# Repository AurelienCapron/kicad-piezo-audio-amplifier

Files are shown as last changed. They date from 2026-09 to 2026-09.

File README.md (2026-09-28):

# Chaîne d'Amplification Audio Piézoélectrique & PCB CMS (KiCad 9)





Conception, simulation SPICE, routage PCB en composants montés en surface (CMS) et caractérisation expérimentale d'une chaîne complète de conditionnement et d'amplification audio pour capteur piézoélectrique (guitare acoustique, contrebasse). Le système est alimenté en asymétrique (0V/5V) et réparti sur deux cartes électroniques : une première dédiée à la préamplification et à l'égalisation active (filtre de Baxandall), et une seconde intégrant une correction physiologique (*Loudness*) ainsi que deux étages de puissance sélectionnables (Classe AB et Classe D) pour piloter un haut-parleur de 8 Ω (2 W).

* **[Consulter le rapport complet de caractérisation et fiches de mesures (PDF)](docs/characterization_report.pdf)**

---

## Sommaire
1. [Architecture globale et cartes PCB réalisées](#architecture-globale-et-cartes-pcb-réalisées)
2. [Structure du dépôt](#structure-du-dépôt)
3. [Conception électronique détaillée (Cartes 1 et 2)](#conception-électronique-détaillée-cartes-1-et-2)
4. [Caractérisation expérimentale et résultats](#caractérisation-expérimentale-et-résultats)
5. [Nomenclature des composants principaux (BOM)](#nomenclature-des-composants-principaux-bom)
6. [Ouverture des fichiers de conception (KiCad 9)](#ouverture-des-fichiers-de-conception-kicad-9)

---

## Architecture globale et cartes PCB réalisées

Architecture de la chaîne audio

| Carte PCB 1 soudée (Préampli, Baxandall & Alim 5V) | Carte PCB 2 soudée (Loudness, Classe AB & Classe D) |
| :---: | :---: |
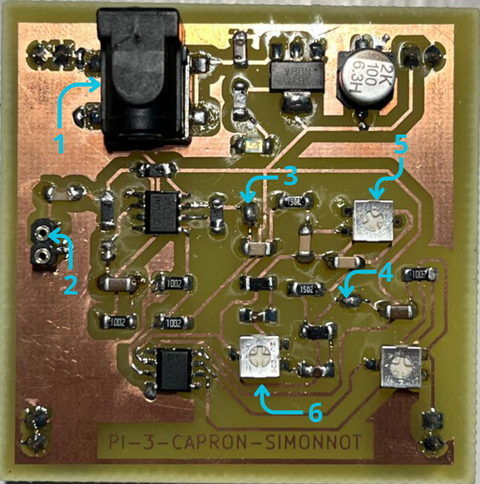
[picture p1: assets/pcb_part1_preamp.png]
PCB 1
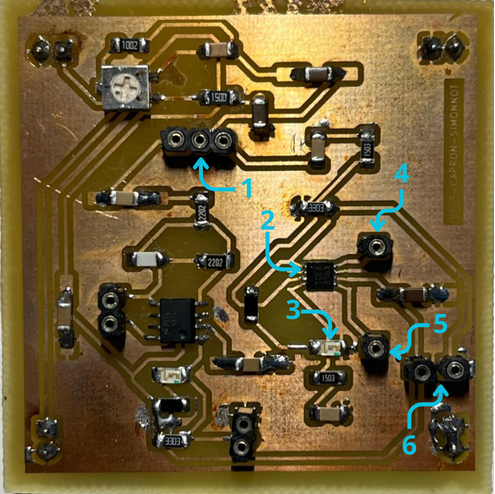
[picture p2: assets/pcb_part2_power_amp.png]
PCB 2
|  |  |
| *AOP ST TSV912IDT (SOIC-8), régulateur LDO 5V (SOT-223) et potentiomètres Vishay TS53YL* | *Ampli Classe AB TS4871 (SOIC-8), Ampli Classe D TS4962 (DFN-8) et cavalier de sélection* |

---

## Structure du dépôt

```text
kicad-piezo-audio-amplifier/
├── .gitignore
├── README.md
├── assets/
│   ├── audio_chain_architecture.svg  # Schéma synoptique vectoriel des 2 cartes PCB
│   ├── baxandall_bode_boost.png      # Diagramme de Bode expérimental (Modes Boost)
│   ├── baxandall_bode_cut.png        # Diagramme de Bode expérimental (Modes Cut)
│   ├── baxandall_schematic.png       # Schéma KiCad du filtre actif de Baxandall
│   ├── class_d_pwm_envelope.png      # Capture Tektronix : signal audio 300 Hz et enveloppe PWM
│   ├── class_d_pwm_zoom_neg.png      # Capture Tektronix : découpage PWM sur alternance négative
│   ├── class_d_pwm_zoom_pos.png      # Capture Tektronix : découpage PWM sur alternance positive
│   ├── pcb_part1_preamp.png          # Carte PCB 1 soudée en CMS
│   └── pcb_part2_power_amp.png       # Carte PCB 2 soudée en CMS
├── docs/
│   └── characterization_report.pdf   # Fiches de mesures complètes (Baxandall & Classe D)
└── hardware_kicad/
    ├── BE-Elec-S2.kicad_pro          # Fichier de projet KiCad 9.0
    ├── BE-Elec-S2.kicad_sch          # Schéma racine hiérarchique
    ├── Partie-1.kicad_sch            # Schéma Carte 1 (Préampli, Baxandall, Volume, Alim)
    ├── Partie-2.kicad_sch            # Schéma Carte 2 (Loudness, Ampli Classe AB & Classe D)
    └── BE-Elec-S2.kicad_pcb          # Routage PCB complet (empreintes CMS 1206, SOIC-8, DFN-8)
```

---

## Conception électronique détaillée (Cartes 1 et 2)

### 1. Carte PCB 1 : Alimentation, Préamplification et Égaliseur de Baxandall
La première carte assure l'adaptation d'impédance du disque piézoélectrique et la mise en forme spectrale du signal avec une excursion maximale de sortie de $5\text{ V}_{\text{pp}}$ :
* **Régulation 5V et masse virtuelle ($V_{\text{ref}} = 2,5\text{ V}$) :** Un régulateur LDO `TLV1117-50` (`LD1117`, boîtier SOT-223) abaisse la tension d'entrée 12V vers un rail régulé `VCC = 5V`. L'alimentation étant asymétrique (0V/5V), une polarisation à $V_{\text{ref}} = \text{VCC}/2 = 2,5\text{ V}$ est générée par ponts diviseurs (`R1`/`R2` de $100\text{ k}\Omega$ et `R3`/`R4` de $10\text{ k}\Omega$) pour centrer le signal audio et éviter tout écrêtage des alternances négatives.
* **Étage suiveur et préamplificateur (`U1` — ST `TSV912IDT`) :** Le signal issu du capteur piézoélectrique traverse un condensateur de couplage (`C1 = 1 µF`), passe par un amplificateur opérationnel monté en suiveur (`U1A`) offrant une haute impédance d'entrée, puis est amplifié par un montage inverseur (`U1B`, `R5 = 10 kΩ`, `R6 = 100 kΩ`) fixant un gain en tension de $\vert{}A_v\vert{} = R_6 / R_5 = 10$ (+20 dB).
* **Correcteur de tonalité actif de Baxandall (`U2A` — ST `TSV912IDT`) :** Réseau actif RC et potentiométrique permettant un réglage indépendant des graves et des aigus autour d'une fréquence charnière fixée à **1 kHz** :
  * **Voie Graves (Bass) :** Potentiomètre `RV1 = 50 kΩ`, résistances `RB1 = RB2 = 15 kΩ` et condensateurs `CB1 = CB2 = 33 nF`.
  * **Voie Aigus (Treble) :** Potentiomètre `RV2 = 50 kΩ`, résistances `RT1 = RT2 = 3,3 kΩ` et condensateurs `CT1 = CT2 = 3,3 nF`.

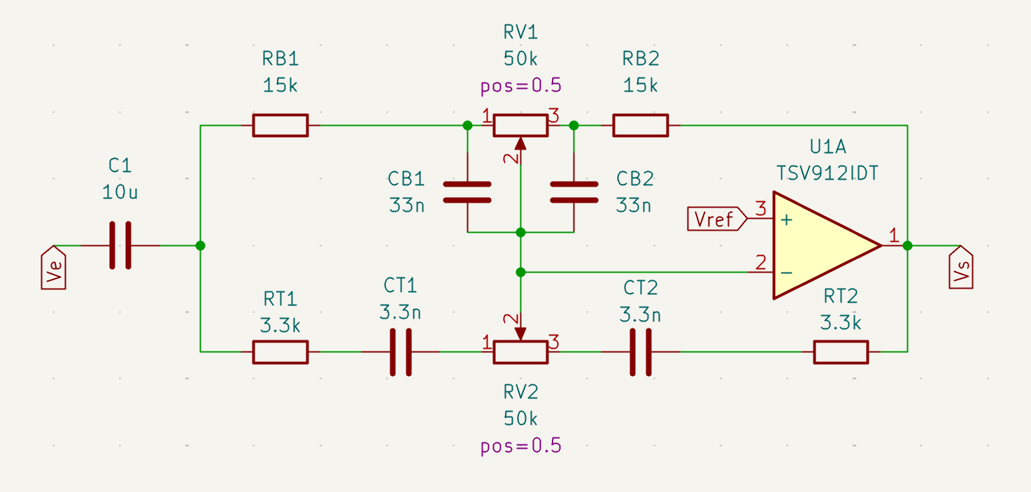
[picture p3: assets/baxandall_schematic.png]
Schéma KiCad du filtre de Baxandall


* **Contrôle de volume actif (`U2B` — ST `TSV912IDT`) :** Montage inverseur à gain variable (`R7 = 10 kΩ` en entrée et potentiomètre `RV3 = 50 kΩ` en contre-réaction) permettant d'ajuster le niveau injecté vers la carte de puissance.

### 2. Carte PCB 2 : Correcteur Loudness et Amplification Classe AB / Classe D
* **Correcteur physiologique (*Loudness*) :** Filtre passif RC associé au potentiomètre `RV5 = 10 kΩ` (`R10 = 120 Ω`, `R11 = 10 kΩ`, `C9 = 15 µF`, `C10 = 180 pF`) compensant la perte de sensibilité de l'oreille humaine aux extrémités du spectre sonore (basses et hautes fréquences) à faible volume d'écoute.
* **Amplificateur de puissance Classe AB (`U_AB1` — ST `TS4871IDT`) :** Amplificateur audio linéaire Rail-to-Rail 1 W en boîtier SOIC-8 configuré avec une résistance d'entrée `Rin1 = 22 kΩ` et une contre-réaction `Rfeed1 = 22 kΩ` (`Cfeed1 = 330 pF`).
* **Amplificateur de puissance Classe D (`U_D1` — ST `TS4962`) :** Amplificateur à découpage PWM sans filtre de sortie (*filter-free*) en boîtier miniature `DFN-8` ($3\times3\text{ mm}$). Avec une résistance de contre-réaction interne $R_f = 150\text{ k}\Omega$ et des composants d'entrée $R_8 = R_9 = 150\text{ k}\Omega$ et $C_{s2} = C_{s3} = 100\text{ nF}$, la fréquence de coupure basse et le gain différentiel théorique en topologie pontée (**BTL — Bridge-Tied Load**) valent :

$$f_c = \frac{1}{2\pi R_{\text{in}} C_{\text{in}}} = \frac{1}{2\pi \times 150\times 10^3 \times 100\times 10^{-9}} \approx 10,6\text{ Hz}$$

$$A_v = 2 \times \frac{R_f}{R_{\text{in}}} = 2 \times \frac{150\text{ k}\Omega}{150\text{ k}\Omega} = 2 \quad (+6,02\text{ dB})$$

---

## Caractérisation expérimentale et résultats

Les campagnes de validation ont été réalisées à l'aide d'un générateur de fonctions **GW Instek AFG-2112** et d'un oscilloscope numérique **Tektronix TBS 1052B-EDU**.

### 1. Réponse fréquentielle du filtre de Baxandall (1 Hz – 20 kHz)
Sept configurations des potentiomètres `RV1` (Graves) et `RV2` (Aigus) ont été caractérisées sur banc d'essai avec un signal sinusoïdal d'entrée $V_e = 100\text{ mV}$ :

| Configuration | Position Graves (`RV1`) | Position Aigus (`RV2`) | Gain Graves mesuré | Gain Aigus mesuré | Fréquence de coupure / pivot (-3 dB) |
|---|---|---|---|---|---|
| **1. Neutre (Suiveur)** | 50 % | 50 % | `0,0 dB` | `0,0 dB` | Réponse plate sur `[10 Hz – 20 kHz]` |
| **2. Bass Boost** | 100 % | 50 % | **`+12,6 dB`** | `0,0 dB` | $f_c \approx 100\text{ Hz}$ |
| **3. Treble Boost** | 50 % | 100 % | `0,0 dB` | **`+11,2 dB`** | $f_c \approx 4\text{ kHz}$ |
| **4. Dual Boost** | 100 % | 100 % | **`+12,6 dB`** | **`+11,2 dB`** | Fréquence charnière centrée à `1 kHz (0 dB)` |
| **5. Bass Cut** | 0 % | 50 % | **`-13,0 dB`** | `0,0 dB` | $f_c \approx 300\text{ Hz}$ |
| **6. Treble Cut** | 50 % | 0 % | `0,0 dB` | **`-11,2 dB`** | $f_c \approx 4\text{ kHz}$ |
| **7. Dual Cut** | 0 % | 0 % | **`-13,0 dB`** | **`-11,2 dB`** | Sommet résiduel à `1 kHz (~0 dB)` |

| Réponse fréquentielle en amplification (Boost) | Réponse fréquentielle en atténuation (Cut) |
| :---: | :---: |
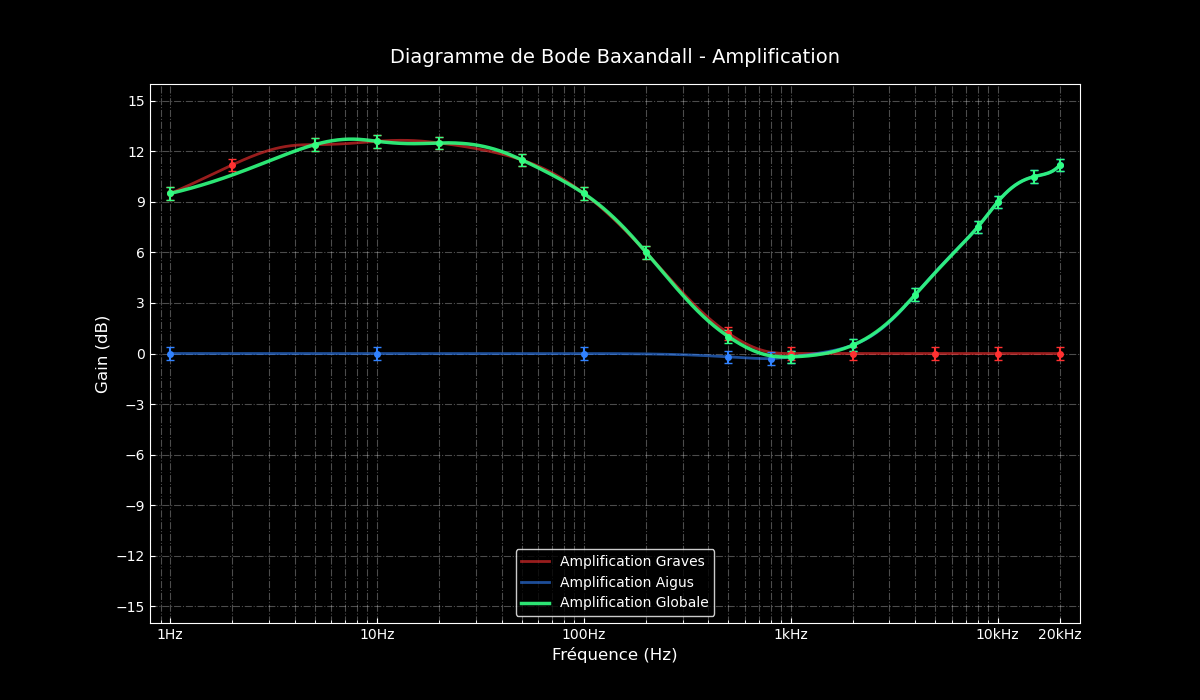
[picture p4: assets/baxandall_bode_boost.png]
Bode Boost
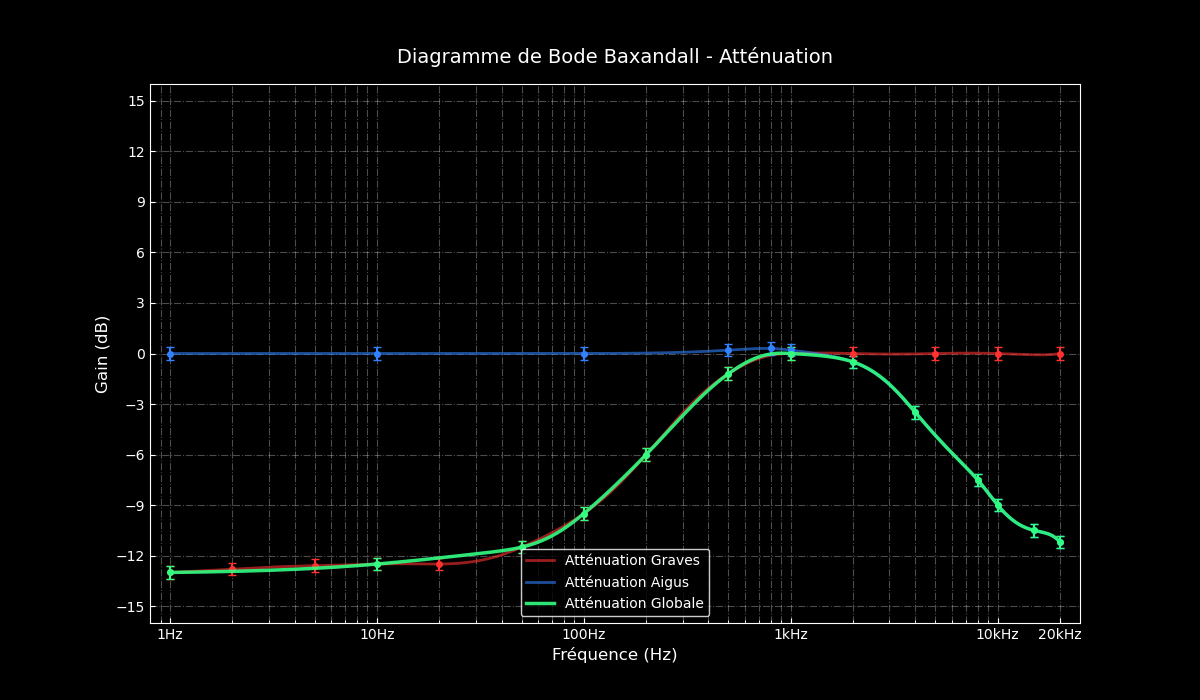
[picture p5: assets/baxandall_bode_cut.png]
Bode Cut
|  |  |

### 2. Caractérisation PWM et mesure différentielle BTL de l'amplificateur Classe D (`TS4962`)
La sortie de l'amplificateur `TS4962` étant pontée (BTL), aucune des deux bornes `OUT+` et `OUT-` ne doit être reliée à la masse de l'oscilloscope sous peine de court-circuiter un demi-pont. La caractérisation a donc été effectuée en mode mathématique différentiel (**`CH2 - CH3`**) avec un signal test à $300\text{ Hz}$ :

| Grandeur caractérisée | Valeur théorique | Valeur expérimentale | Incertitude | Unité |
|---|---|---|---|---|
| Tension d'entrée crête-à-crête ($V_{\text{in}}$) | `280` | **`280`** | $\pm 0,1$ | mV |
| Tension de sortie différentielle BTL ($V_{\text{out}}$) | `560` | **`548`** | $\pm 20$ | mV |
| Gain en tension mesuré ($A_v = V_{\text{out}} / V_{\text{in}}$) | `2,00` | **`1,96`** | $\pm 0,15$ | — |
| Amplitude des créneaux de découpage ($V_{\text{pwm}}$) | `5,00` | **`4,88`** | $\pm 0,10$ | V |
| Fréquence de découpage PWM ($f_{\text{sw}}$) | `250 – 300` | **`266`** | $\pm 15$ | kHz |
| Rapport cyclique au repos ($DC_{\text{repos}}$) | `50,0` | **`50,4`** | $\pm 2,0$ | % |
| Excursion du rapport cyclique ($DC_{\text{min}}$ / $DC_{\text{max}}$) | `< 50` / `> 50` | **`40` / `60`** | $\pm 2,0$ | % |

| Enveloppe PWM globale ($2,50\text{ ms/div}$) | Découpage PWM sur creux négatif ($2,50\ \mu\text{s/div}$) | Découpage PWM sur pic positif ($2,50\ \mu\text{s/div}$) |
| :---: | :---: | :---: |
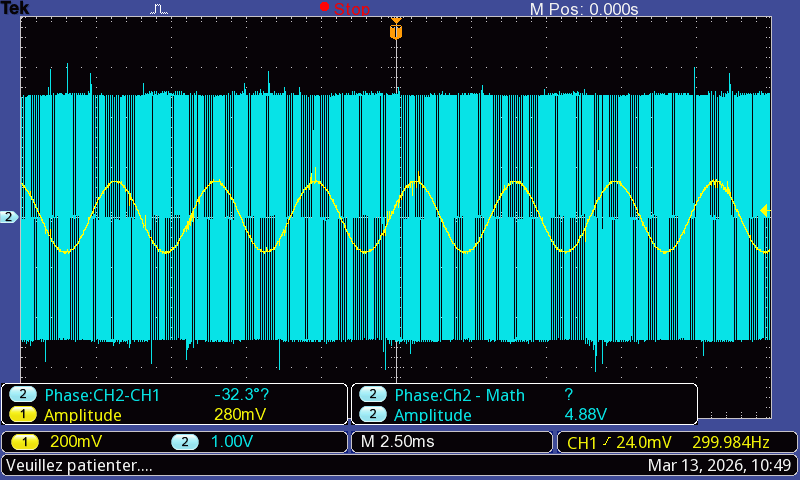
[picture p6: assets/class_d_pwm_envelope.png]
PWM Global
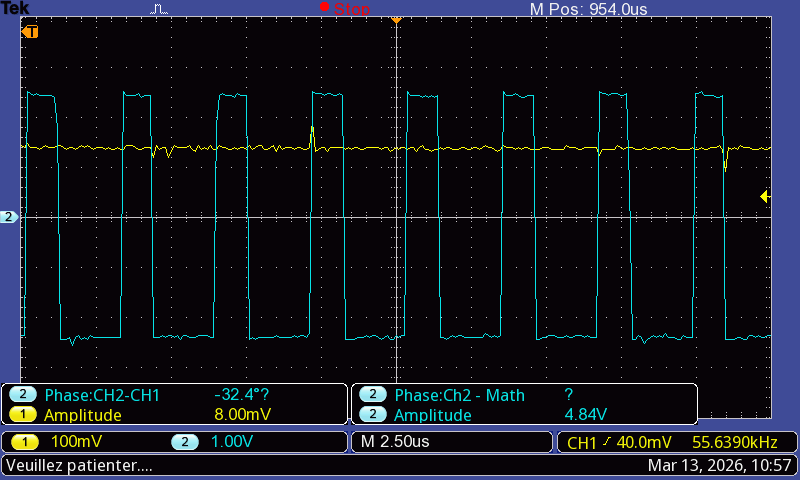
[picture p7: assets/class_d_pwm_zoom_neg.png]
PWM Neg
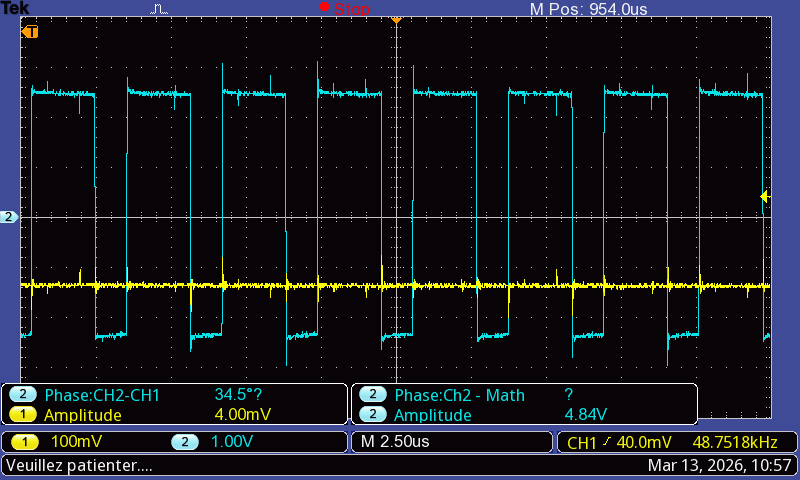
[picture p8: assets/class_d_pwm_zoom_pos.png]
PWM Pos
|  |  |  |
| *Entrée sinusoïdale 300 Hz ($280\text{ mV}_{\text{pp}}$) et découpage BTL* | *Rapport cyclique réduit ($DC_{\text{min}} \approx 40\ \%$)* | *Rapport cyclique élargi ($DC_{\text{max}} \approx 60\ \%$)* |

---

## Nomenclature des composants principaux (BOM)

| Référence | Composant | Fabricant | Boîtier CMS | Fonction |
|---|---|---|---|---|
| **`U1`, `U2`** | `TSV912IDT` | STMicroelectronics | `SOIC-8` | Doubles AOP Rail-to-Rail 8 MHz (Suiveur, Préampli, Baxandall, Volume) |
| **`U_AB1`** | `TS4871IDT` | STMicroelectronics | `SOIC-8` | Amplificateur de puissance audio Classe AB (1 W, BTL, Standby) |
| **`U_D1`** | `TS4962` | STMicroelectronics | `DFN-8` ($3\times3\text{ mm}$) | Amplificateur de puissance audio Classe D sans filtre (2,8 W, PWM 266 kHz) |
| **`U3`** | `TLV1117-50` / `LD1117` | ST / Texas Instruments | `SOT-223` | Régulateur linéaire LDO fixe 5,0 V (800 mA) |
| **`RV1`–`RV3`, `RV5`** | `TS53YL` (50 kΩ / 10 kΩ) | Vishay | CMS Vertical | Potentiomètres cermet (Graves, Aigus, Volume, Loudness) |
| **Passifs `R` / `C`** | Série E6 (`1206`) | Divers | `1206` (3216 Metric) | Résistances, condensateurs céramiques et électrolytiques CMS ($6,3\times5,2\text{ mm}$) |

---

## Ouverture des fichiers de conception (KiCad 9)

1. Installer **KiCad 9.0** (ou version ultérieure).
2. Ouvrir le projet `hardware_kicad/BE-Elec-S2.kicad_pro`.
3. Naviguer dans les deux sous-feuilles hiérarchiques `Partie-1.kicad_sch` et `Partie-2.kicad_sch` depuis l'éditeur de schémas (`eeschema`), ou ouvrir `BE-Elec-S2.kicad_pcb` dans l'éditeur de circuit imprimé (`pcbnew`).

---

## Auteurs

Projet réalisé en binôme par **Aurélien Capron** et **Amaury Simonnot** au sein de **Grenoble INP - Phelma** (Filière Systèmes Électroniques Intégrés / Tronc commun 1A).

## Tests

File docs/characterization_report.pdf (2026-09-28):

Fiches de Mesures – CAPRON – Aurélien / SIMONNOT – Amaury – PI 3

Fiche de mesure : « Correction de tonalité Grave/Aigu Baxandall »

Contexte :

Lors de la transmission du son d'une guitare acoustique, il est essentiel de pouvoir ajuster le rendu sonore selon les préférences de chacun. La perception des basses (fréquences inférieures à 1 kHz) et des aigus (supérieures à 1 kHz) variant d'un individu à l'autre, nous avons opté pour un correcteur de tonalité Baxandall.

Ce système permet à l'utilisateur de régler indépendamment et avec précision ces deux plages de fréquences à l'aide de deux potentiomètres.

Objectif :

Caractériser l'impact des variations résistives d'un correcteur de tonalité Baxandall sur la réponse fréquentielle d'un étage audio.

La campagne de mesures visera spécifiquement à valider les points suivants :

- L'excursion du gain (amplification et atténuation) dans la bande des basses fréquences.
- L'excursion du gain (amplification et atténuation) dans la bande des hautes fréquences.
- Le comportement global du système lors de l'action simultanée des deux étages de correction.
- Le positionnement effectif de la fréquence charnière (ou fréquence pivot) autour de 1 kHz, délimitant l'action respective des deux filtres.

Pour mener à bien cette analyse, sept cas de charge correspondant à différentes positions des potentiomètres (exprimées en pourcentage de leur course) seront étudiés :

1. Bass 50 % / Treble 50 % : Position neutre (comportement en suiveur)
2. Bass 100 % / Treble 50 % : Amplification maximale des basses (boost)
3. Bass 50 % / Treble 100 % : Amplification maximale des aigus (boost)
4. Bass 100 % / Treble 100 % : Amplification maximale sur les deux registres
5. Bass 0 % / Treble 50 % : Atténuation maximale des basses (cut)
6. Bass 50 % / Treble 0 % : Atténuation maximale des aigus (cut)
7. Bass 0 % / Treble 0 % : Atténuation maximale sur les deux registres

Les configurations croisées (ex : amplification d'une bande combinée à l'atténuation de l'autre) n'ont pas été incluses dans ce protocole. En effet, l'analyse de ces cas de figure mettrait simplement en évidence la symétrie de la réponse en fréquence de part et d'autre de la fréquence charnière de 1 kHz, un comportement déjà déductible des sept configurations retenues.

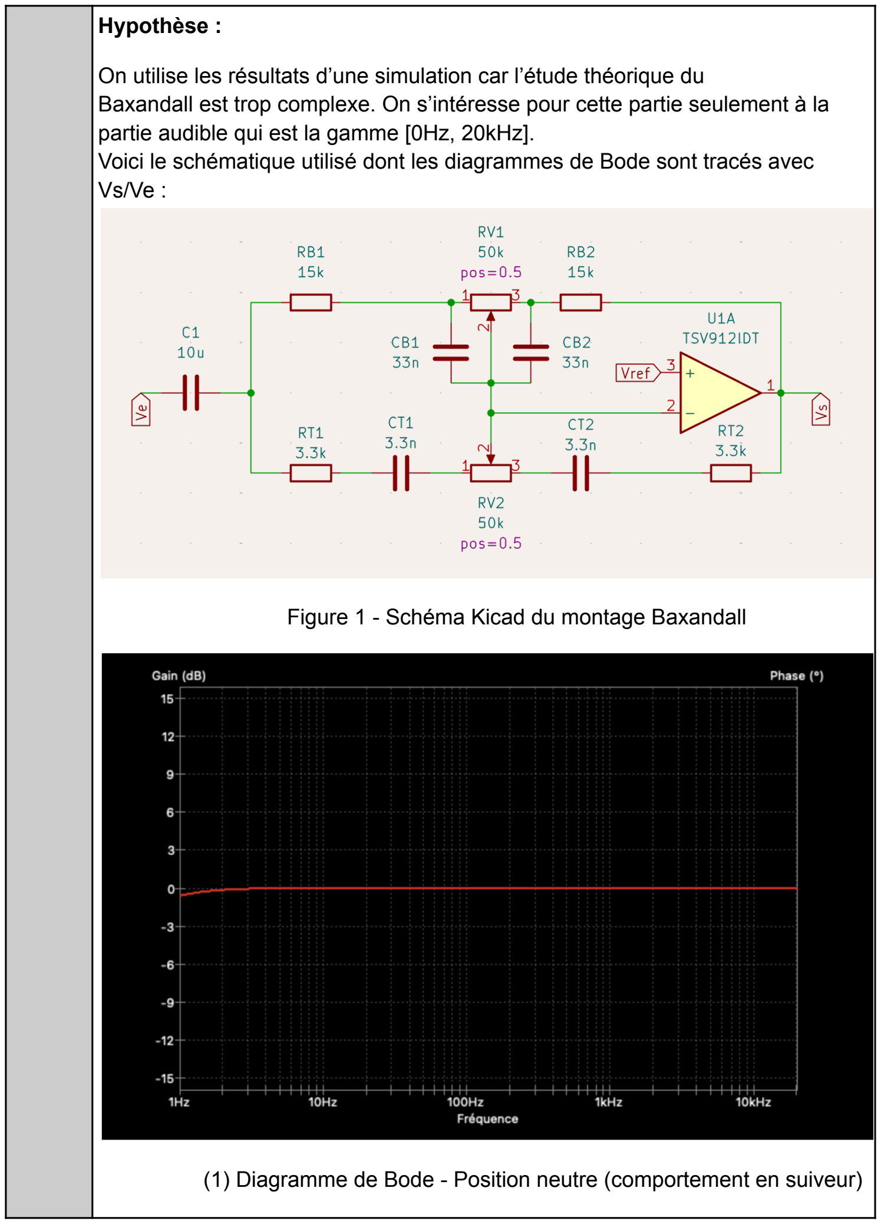
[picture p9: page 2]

Hypothèse :

On utilise les résultats d’une simulation car l’étude théorique du
Baxandall est trop complexe. On s’intéresse pour cette partie seulement à la partie audible qui est la gamme [0Hz, 20kHz].
Voici le schématique utilisé dont les diagrammes de Bode sont tracés avec Vs/Ve :

Figure 1 - Schéma Kicad du montage Baxandall

(1) Diagramme de Bode - Position neutre (comportement en suiveur)

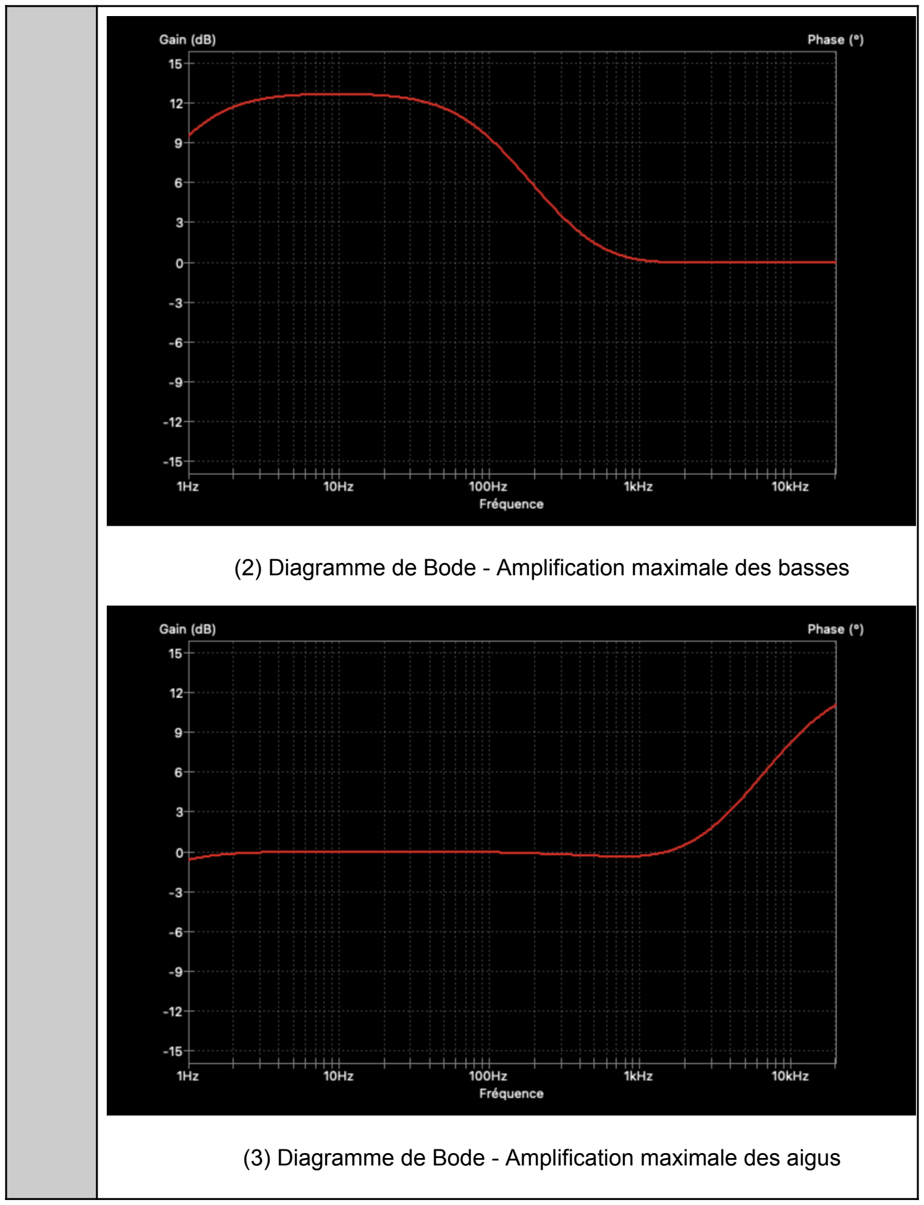
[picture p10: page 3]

(2) Diagramme de Bode - Amplification maximale des basses
(3) Diagramme de Bode - Amplification maximale des aigus

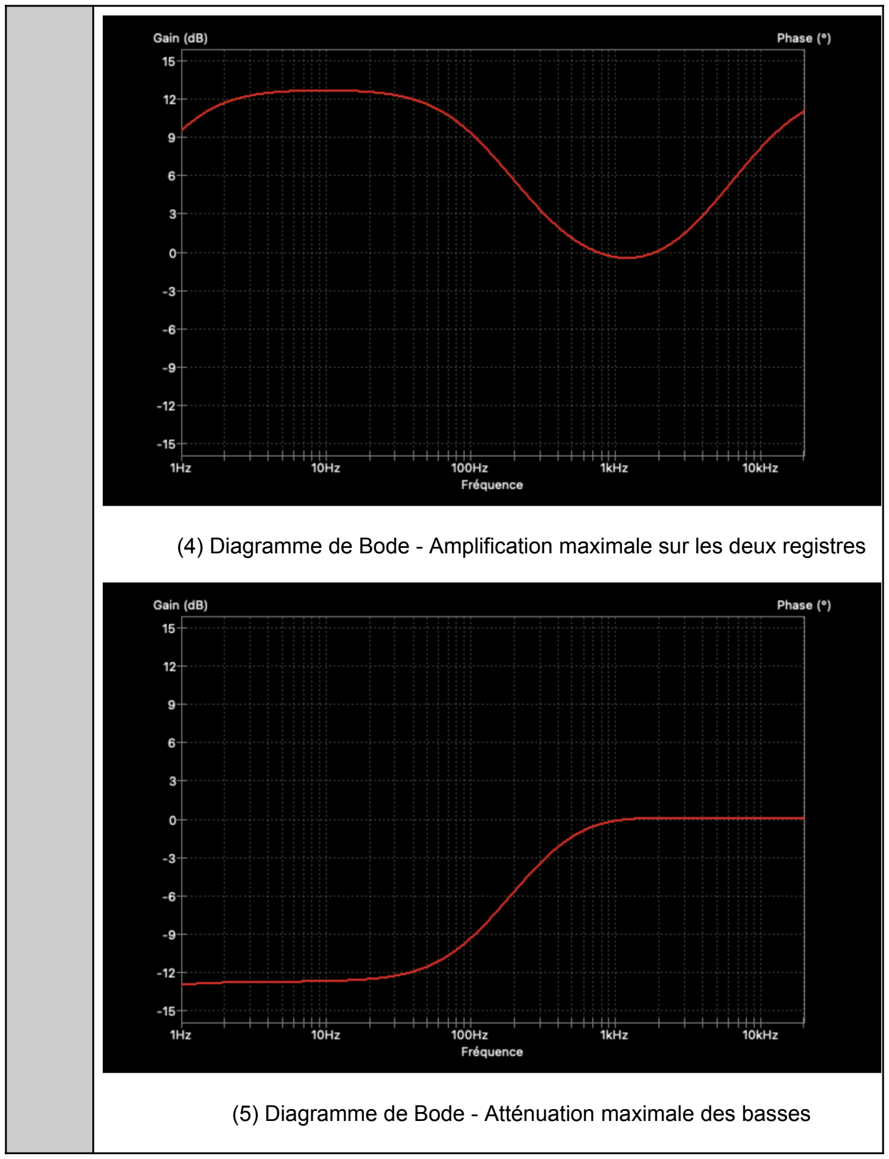
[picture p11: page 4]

(4) Diagramme de Bode - Amplification maximale sur les deux registres
(5) Diagramme de Bode - Atténuation maximale des basses

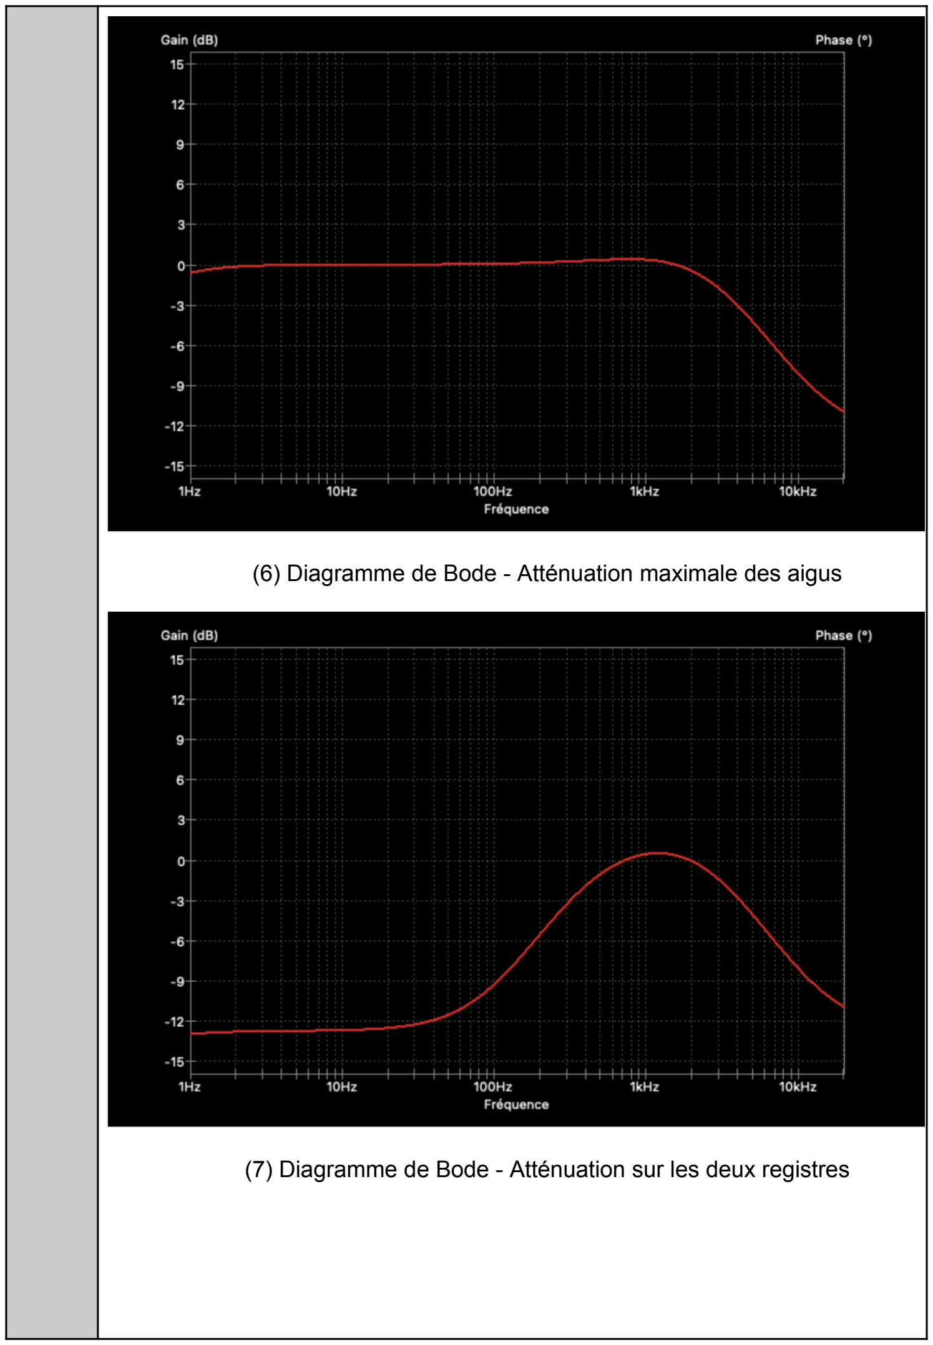
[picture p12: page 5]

(6) Diagramme de Bode - Atténuation maximale des aigus
(7) Diagramme de Bode - Atténuation sur les deux registres

Afin de faciliter la lecture des diagrammes de Bode ci-dessus, le tableau suivant synthétise les gains maximaux et les fréquences d'action pour chaque configuration des potentiomètres :

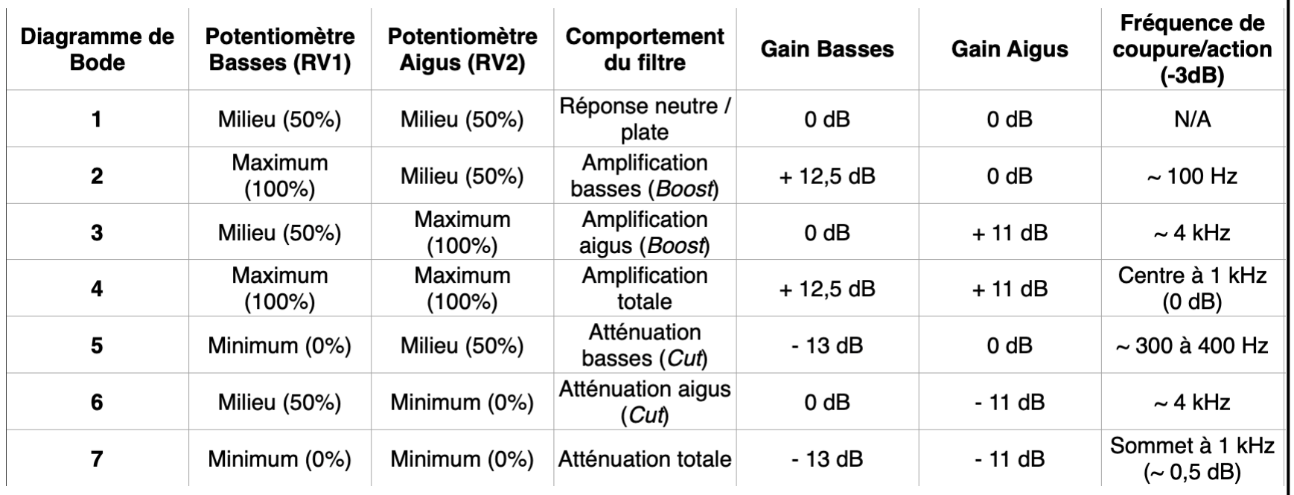
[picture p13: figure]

Tableau 1 - Récapitulatif des gains et fréquences de coupure du correcteur de tonalité.

Principe de manipulation :

Les mesures réalisées ont pour but de caractériser la réponse en fréquence du correcteur de tonalité : relever les gains extrêmes (Vs/Ve) d'amplification et d'atténuation pour les graves et les aigus, vérifier la neutralité de la bande passante centrale (1 kHz), et déterminer les fréquences de coupure (Fc) à -3dB pour chaque réglage.

Matériel et appareils de mesures :

- GBF GW Instek AFG-2112
- Oscilloscope Tektronix 1052B-EDU
- Sondes de mesure
- Câbles BNC
- PCB avec le schéma (cf. figure 1)

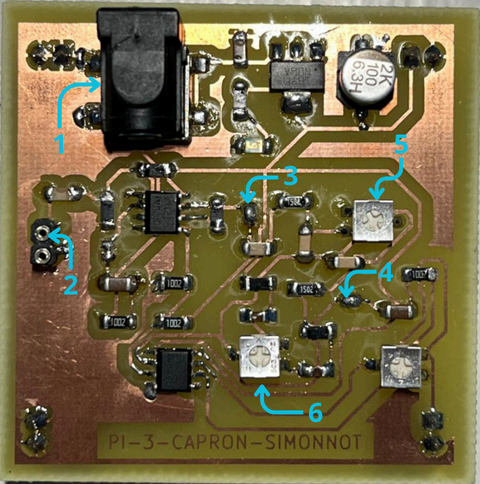
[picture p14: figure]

Figure 2 - Première partie plaque PCB

1. Alimentation de la carte en 5V
2. Jumper du signal d’entrée (la masse sera commune aux différents appareils avec le pin du bas)
3. Emplacement de la mesure avec la sonde de Ve
4. Emplacement de la mesure avec la sonde de Vs
5. Potentiomètre de réglage des basses fréquences
6. Potentiomètre de réglage des hautes fréquences

Mode opératoire :

### 1. Câblage du montage

- Réaliser les branchements décrits sur le schéma précédent, en veillant rigoureusement à relier toutes les masses en un point commun.
- Connecter la voie 1 (CH1) de l'oscilloscope en parallèle de la sortie du GBF pour mesurer le signal d'entrée (Ve).
- Connecter la voie 2 (CH2) de l'oscilloscope à la sortie du circuit pour mesurer le signal de sortie (Vs).

### 2. Paramétrage des instruments de mesure

- Générateur (GBF) : Configurer un signal sinusoïdal, sans offset, avec une amplitude de 100 mV. La fréquence sera la variable d'ajustement.
- Oscilloscope : Régler les deux voies en couplage AC.
- Activer les mesures automatiques des tensions crête-à-crête pour CH1 et CH2 afin de pouvoir calculer le gain (VCH2/VCH1).
- Ajuster en permanence les calibres verticaux et la base de temps lors du balayage pour toujours afficher plusieurs périodes complètes à l'écran et maximiser la précision.

### 3. Procédure de relevé expérimental

- Positionner les deux potentiomètres (basses et aigus) sur la première des 7 configurations définies dans les objectifs.
- Balayer rapidement les fréquences avec le GBF pour repérer le gain maximum (ou minimum) propre à cette configuration.
- Rechercher et relever la (ou les) fréquence(s) de coupure à -3 dB par rapport à ce gain de référence.
- Effectuer une série de mesures point par point pour tracer la courbe, en utilisant une progression logarithmique
- Répéter cette procédure (recherche du gain max, des Fc, puis relevé par décade) pour les 6 autres positions des potentiomètres.

Mesures :
Afin de caractériser l'action du correcteur de tonalité, les mesures de la tension de sortie par rapport à la fréquence ont été répertoriées ci-dessous.

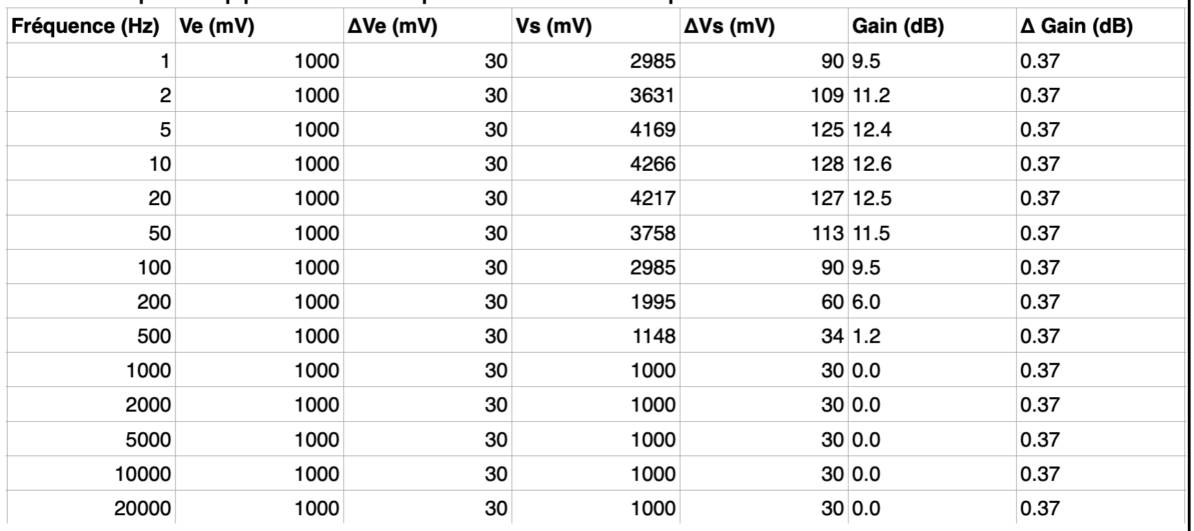
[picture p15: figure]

Tableau 1 : Relevé expérimental – Amplification maximale des basses fréquences

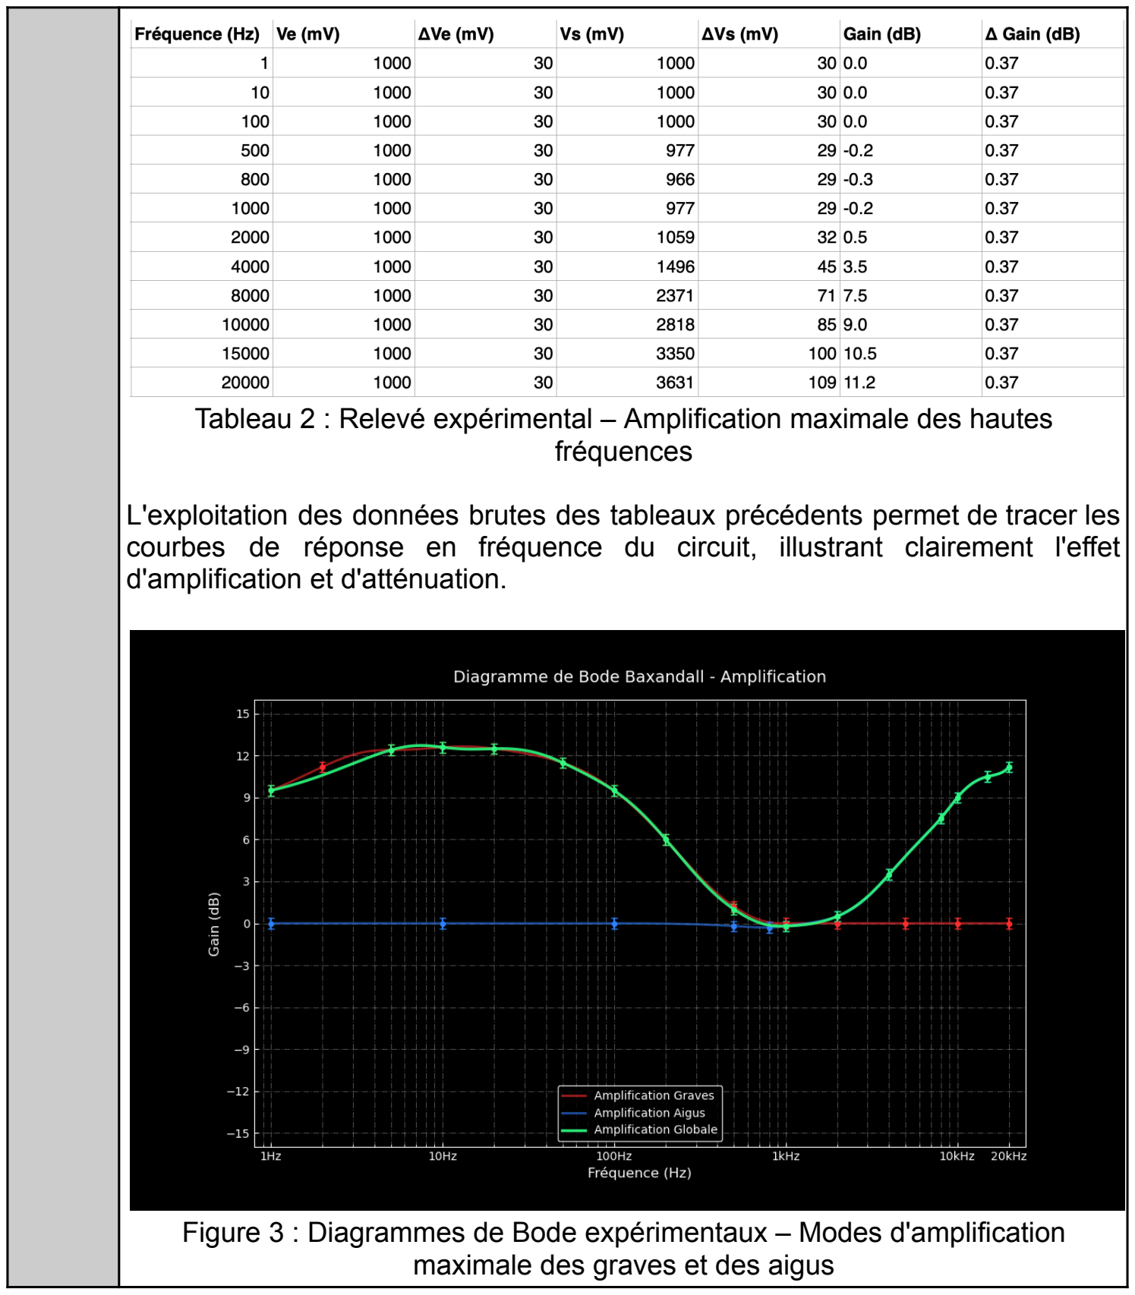
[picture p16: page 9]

Tableau 2 : Relevé expérimental – Amplification maximale des hautes fréquences

L'exploitation des données brutes des tableaux précédents permet de tracer les courbes de réponse en fréquence du circuit, illustrant clairement l'effet d'amplification et d'atténuation.

Figure 3 : Diagrammes de Bode expérimentaux – Modes d'amplification maximale des graves et des aigus

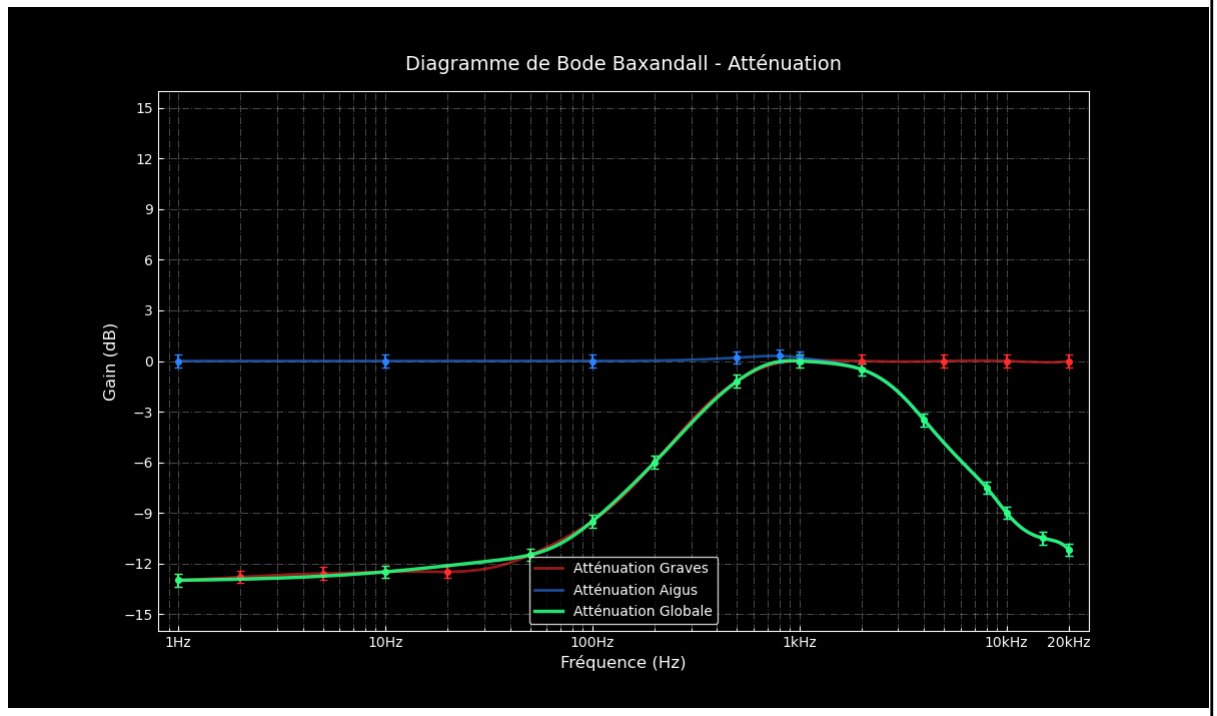
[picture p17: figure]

Figure 4 : Diagrammes de Bode expérimentaux – Modes d'atténuation maximale des graves et des aigus.
Description de la mesure :
(1) Position neutre (50/50) : Le gain est parfaitement constant à 0 dB sur la quasi-totalité de la bande audio. On observe cependant une très légère atténuation sur le tout premier point de mesure (autour de 1 Hz). Cela s'explique par la présence du condensateur de liaison en entrée du circuit (C1 = 10 µF) qui se comporte comme un filtre passe-haut et coupe la composante continue.
(2) Amplification maximale des graves (Bass Boost) : On obtient un plateau d'amplification en basse fréquence avec un gain maximum de +12,6 dB et une fréquence de coupure à -3 dB d'environ 100 Hz. L'allure de la courbe est parfaitement conforme à la théorie. L'amplitude d'entrée de 0,10 V ayant été bien choisie, l'amplificateur opérationnel reste en régime linéaire et aucune saturation ne vient déformer la mesure (la tension de sortie n'atteignant que 0,42 V crête).
(3) Amplification maximale des aigus (Treble Boost) : La courbe présente un gain maximum de +11,2 dB aux plus hautes fréquences mesurées (20 kHz), avec une fréquence d'action débutant autour de 4 kHz. L'écart avec le modèle de simulation est négligeable (inférieur à 5%).
(4) Amplification globale (Bass + Treble Boost) : Cette courbe illustre parfaitement le principe de superposition du montage de Baxandall. Pour les fréquences inférieures à 100 Hz, la courbe se superpose exactement à (2), et pour les fréquences supérieures à 4 kHz, elle se superpose à (3). Le gain redescend précisément à 0 dB à la fréquence centrale de 1 kHz.
(5) Atténuation maximale des graves (Bass Cut) : Le gain minimum atteint un plateau à -13 dB pour les fréquences inférieures à 100 Hz. La fréquence de coupure se situe légèrement plus haut que lors de l'amplification (autour de 300

Hz), ce qui est un comportement caractéristique des tolérances réelles des composants passifs (potentiomètres et condensateurs) utilisés sur la carte.
(6) Atténuation maximale des aigus (Treble Cut) : De la même manière que pour (3), la symétrie est respectée avec une atténuation atteignant -11,2 dB à 20 kHz et une pente qui s'amorce autour de 4 kHz.
(7) Atténuation globale (Bass + Treble Cut) : Tout comme pour (4), on retrouve la superposition des filtres (5) et (6). La bande passante est fortement atténuée aux extrémités, laissant uniquement passer les fréquences médiums avec un léger pic résiduel autour de 1 kHz (gain très proche de 0 dB). Le très léger écart sur le premier point à 1 Hz est, là encore, la signature du condensateur de liaison passe-haut en entrée.

Par ailleurs, le caractère inverseur du circuit a pu être vérifié expérimentalement, validant ainsi un aspect supplémentaire de la simulation.

Analyse et conclusion :

Les résultats expérimentaux obtenus sont globalement très satisfaisants et parfaitement conformes aux attentes théoriques. Le circuit remplit bien son rôle de correcteur de tonalité (Baxandall) : la manipulation du potentiomètre des graves (RV1) permet d'amplifier ou d'atténuer efficacement la bande des basses fréquences, tandis que le second potentiomètre agit indépendamment sur les aigus. La zone centrale (autour de 1 kHz) reste stable. Dans la plage de fréquences la plus utile à l'oreille humaine [100 Hz - 20 kHz], l'écart entre nos mesures et la simulation informatique reste minime (inférieur à 5-10%).

On note cependant une légère divergence par rapport au modèle théorique idéal pour les fréquences situées en dessous de 100 Hz, où le gain chute légèrement. Cela s'explique par la présence du condensateur de liaison en entrée du circuit, qui agit comme un filtre passe-haut non modélisé dans notre simulation initiale. Toutefois, d'un point de vue purement acoustique, cet écart n'est pas problématique : l'oreille humaine est beaucoup moins sensible aux fréquences extrêmes (sub-basses), rendant cette atténuation pratiquement inaudible en condition réelle d'écoute.

L'analyse de ces mesures nous permet également de poser un regard critique sur le dimensionnement de nos composants. Nous avons opté pour un potentiomètre de 50 kΩ pour les graves, ce qui génère un gain maximal très important (+12,6 dB). Si notre montage de test (alimenté avec un petit signal de 0,10 V) a parfaitement fonctionné, l'utilisation de cette carte avec une source audio standard (ex: lecteur MP3 ou instrument délivrant un signal plus fort) risque d'entraîner une saturation de l'amplificateur opérationnel.

Ainsi, pour éviter tout phénomène d'écrêtage (distorsion du son), il est recommandé à l'utilisateur de ne pas dépasser 80% de la course du potentiomètre des graves. À l'inverse, la valeur du potentiomètre des aigus semble légèrement sous-dimensionnée selon l'effet recherché. Une révision future du circuit pourrait inclure un ajustement de ces résistances variables pour optimiser la dynamique du système.

Fiche de mesure : « Amplificateur classe D »

Contexte :

Le cahier des charges (CDC) du projet demande de concevoir une chaîne d'amplification pour un instrument acoustique, capable de piloter un haut-parleur.

Pour l'étage de puissance, le choix s'est porté sur un amplificateur de Classe D (modèle TS4962) plutôt qu'un Classe AB. L'intérêt théorique majeur de la Classe D est son rendement énergétique très élevé.

Au lieu de fonctionner en régime linéaire (ce qui dissipe beaucoup de chaleur), les transistors de sortie fonctionnent en commutation (bloqué ou saturé). Le signal d'entrée analogique est converti en un signal carré haute fréquence par Modulation de Largeur d'Impulsion (PWM).

Le haut-parleur lisse ensuite ce signal pour restituer l'audio. De plus, cet amplificateur possède une sortie en pont (BTL - Bridge-Tied Load), nécessitant une précaution particulière lors de la mesure.
Objectif :
- Visualiser et comprendre la conversion du signal analogique en signal PWM (commutation).
- Mesurer le gain de l'étage d'amplification de puissance.
- Réaliser une mesure différentielle sécurisée sur une topologie BTL (sans court-circuiter la sortie à la masse de l'oscilloscope).

Hypothèses :

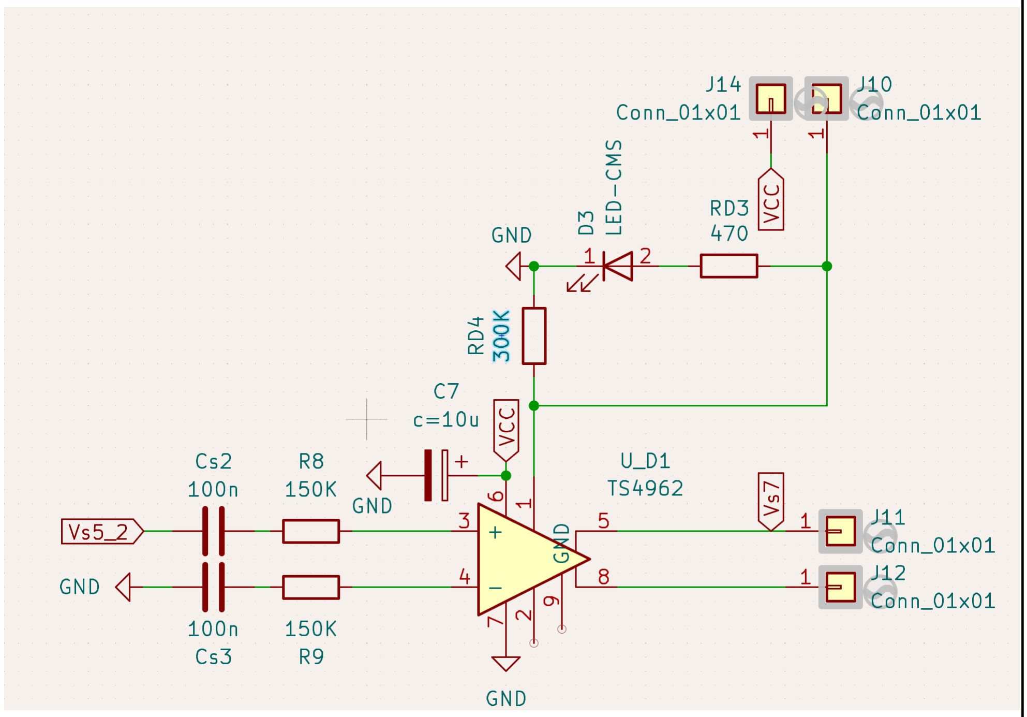
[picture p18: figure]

Figure 1 - Schéma Kicad du montage amplificateur classe D

- Composants d'entrée :
Les résistances d'entrée sont R | et les condensateurs de
8 = R

9 = 150kΩ
liaison sont C | . De plus, nous avons une résistance de
s2 = C

s3 = 100nF
contre-réaction interne R | .
f = 150kΩ
- Fréquence de coupure basse :
Le filtre passe-haut d'entrée a pour fréquence de coupure : f

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
2×Π×150000×100×10

−9 = 10. 6

Notre signal de test ayant été réglé à 300 Hz pendant la manipulation, il reste très supérieur à cette fréquence de coupure (environ 10.6 Hz). Il ne subira aucune atténuation par le filtre d'entrée.

- Gain théorique (Sortie BTL) :
La tension de sortie différentielle donne un gain :

A

v = 2 ×

R
f
R
in

= 2 ×

150
150 = 2
(soit un gain G = 20log | .
10
(2) ≃ 6. 02dB)
Pour un signal d'entrée de 280 mV crête-à-crête, nous obtiendrons un signal utile en sortie d'amplitude V
out = 2 × 280 mV = 560 mV
crête-à-crête (soit 0.56V).

- Comportement PWM :

L'observation directe d'une broche de sortie montrera un signal haché haute fréquence. La largeur de l'état haut s'élargira lors des pics positifs du signal d'entrée, et la largeur de l'état bas s'élargira lors des pics négatifs (principe de la modulation de largeur d'impulsion).

Principe de manipulation :

Un signal sinusoïdal de test basse fréquence est injecté à l'entrée de l'amplificateur Classe D via un Générateur Basses Fréquences (GBF). À l'aide d'un oscilloscope numérique, nous relevons simultanément le signal de référence en entrée et le comportement de l'étage de puissance en sortie. L'expérience se déroule en deux phases :

1. Analyse du découpage : Observation directe du signal haute fréquence sur une seule broche de sortie pour valider et caractériser la Modulation de Largeur d'Impulsion (PWM).
2. Analyse de l'amplification : Utilisation de la fonction Mathématique de l'oscilloscope pour réaliser une mesure différentielle sur la topologie en pont (BTL) de la sortie, permettant d'isoler et d'évaluer virtuellement le signal utile amplifié.

Matériel et appareils de mesures :

- GBF GW Instek AFG-2112
- Oscilloscope Tektronix 1052B-EDU
- Sondes de mesure
- Câbles BNC
- PCB avec le schéma (cf. figure 1)


Figure 2 - Deuxième partie plaque PCB

1. Jumper pour choisir l’utilisation de l’amplificateur de classe AB ou de classe D (de gauche à droite : ampli classe AB; sortie Loudness; ampli classe D)
2. Amplificateur classe D
3. LED témoin s’allumant lors de l’alimentation de l’amplificateur classe D
4. Borne de sortie positive de l’amplificateur
5. Borne de sortie négative de l’amplificateur
6. Standby de l’amplificateur (alimentation par connection des pins) Mode opératoire :

### 1. Mise sous tension : Alimenter la carte électronique avec une

source de tension continue fixée à 5 V.

2. Distribution d'énergie et routage des signaux : Alimenter l’amplificateur classe D à l’aide du jumper 6 (vérification que la LED témoin soit allumée) et choix du chemin électrique à l’aide du jumper 1 (connection entre le pin 2 et 3).

### 3. Injection du signal : Configurer le GBF pour injecter le signal

sinusoïdal de test à l'entrée du montage (fréquence de 300 Hz et
amplitude mesurée V | crête-à-crête).
in = 280 mV
4. Acquisition de référence : Connecter la sonde de la voie 1 (CH1, trace jaune) de l'oscilloscope sur l'entrée pour acquérir le signal de référence.
5. Observation du PWM : Connecter la sonde de la voie 2 (CH2, trace bleue) sur la broche de sortie OUT+ (cf. figure 2). Varier la base de temps de l'oscilloscope pour réaliser une vue macroscopique (ex: 2.50 ms/div) de l'enveloppe, puis des vues microscopiques (ex: 2.50 µs/div) pour mesurer la fréquence de découpage et les rapports cycliques.

### 6. Configuration pour la mesure de gain (Méthode différentielle) :

Connecter une troisième sonde (CH3) sur la broche OUT- (cf. figure 2). Activer la fonction Mathématique de l'oscilloscope et sélectionner
l'opération de soustraction (CH2 - CH3) pour annuler la tension de mode commun du pont.


Mesures :

- Formes d'onde de la modulation PWM :

Figure 3 - Signal sur pic négatif

Figure 4 - Signal sur pic positif


Figure 5 - Signal entier

- Tableau de mesures :
Grandeur mesurée | Valeur estimée | Valeur relevée | Incertitude estimée | Unité
Tension d'entrée Vin (crête-crête) | 280 | 280 | ± 0. 1 | mV
Tension de sortie diff. Vout | 560 | 548 | ± 20 | mV
Gain mesuré Av | 2 | 1. 96 | ± 0. 15 | −
Amplitude du signal V pwm | 5 | 4. 88 | ± 0. 1 | V
Fréquence de découpagef sw | 250 à 300 | 266 | ± 15 | kHz
Rapport cyclique (sans signal) DC repos | 50 | 50. 4 | ± 2 | %
Rapport cyclique (pic max) DC max | > 50 | 60 | ± 2 | %
Rapport cyclique (pic min) DC min | < 50 | 40 | ± 2 | %

Description de la mesure :

Les observations qualitatives des chronogrammes nous ont permis de relever et d'estimer les grandeurs consignées dans le tableau de mesures ci-dessus.

### 1. Paramètres d'entrée et mesure du Gain (Basse Fréquence) :

En observant la trace jaune sur la capture globale (cf. figure 5), on lit une tension d'entrée de référence V de 280 mV crête-à-crête à une fréquence
in
propre d'environ 300 Hz. Lors de la manipulation sur le banc d'essai, l'activation de la fonction Mathématique (CH2 - CH3) de l'oscilloscope nous a permis de visualiser l'enveloppe différentielle de sortie. Nous avons pu y relever une tension V de 548 mV crête-à-crête. Le calcul du gain expérimental nous
out
donne ainsi la valeur A | (soit 548 / 280).
v = 1. 96

### 2. Caractéristiques du signal haché (Haute Fréquence) :

La trace bleue de la figure 4 montre le signal de découpage brut sur la broche OUT+. La mesure automatique de l'oscilloscope y indique une amplitude V de
pwm
4.88 V. Cette valeur confirme visuellement que le signal commute de façon quasi-parfaite entre 0V et la tension d'alimentation de la carte (5V). De plus, l'échelle de temps des vues zoomées (figures 3 et 4 à 2.50 µs/div) permet de mesurer la période d'un cycle à environ 3.75 µs. Cela justifie la fréquence de découpage f de 266 kHz relevée dans le tableau.
sw

### 3. Évolution du rapport cyclique (Modulation) :

Enfin, la comparaison des figures 3 et 4 illustre la variation du rapport cyclique qui encode notre signal audio :

- Au point de repos (lorsque l'entrée croise 0 V), le signal carré est symétrique, ce qui correspond à la valeur DC estimée à environ 50 %.
repos
- Sur le pic positif du signal d'entrée (cf. figure 4), l'observation qualitative montre que l'état haut s'élargit fortement, justifiant la valeur mesurée de
DC | . max ≃ 60%
- Sur le creux négatif du signal d'entrée (cf. figure 3), c'est l'inverse : l'état bas prédomine visuellement, faisant chuter le rapport cyclique à la valeur mesurée de DC
min ≃ 40%

Critique :

- Limites de la mesure différentielle : La détermination du gain A a
v
nécessité l'utilisation de la fonction mathématique numérique (CH2 -CH3) de l'oscilloscope afin de réaliser une mesure différentielle sur la topologie BTL. Cette méthode de soustraction interne introduit un bruit de quantification qui vient s'ajouter au résidu de découpage haute fréquence propre à la Classe D.
- Incertitudes : Ce phénomène se traduit par une épaisseur importante de la trace reconstituée à l'écran. La lecture de l'amplitude crête-à-crête de la sinusoïde de sortie est donc délicate, ce qui justifie notre incertitude estimée à ± 20mV sur la mesure de V , et par conséquent une
out
incertitude de ± 0. 15 sur le calcul du gain expérimental.
- Amélioration matérielle : Pour pallier cette limite de l'instrument de mesure, l'insertion d'un filtre passe-bas passif matériel juste avant les sondes permettrait de lisser physiquement le signal haute fréquence et d'obtenir une trace parfaitement nette pour la lecture du gain.

Analyse et conclusion :

L'objectif de visualiser et comprendre la conversion analogique/PWM de l'étage de puissance est pleinement atteint.

- Validation du système : Le gain expérimental mesuré en direct à 1.96 est très cohérent avec le gain théorique de 2 défini par le dimensionnement de nos résistances d'entrée.
- Validation du principe : L'amplitude du signal haché mesurée à 4.88 V confirme que les transistors fonctionnent exclusivement en commutation (bloqué/saturé). La puissance dissipée sous forme de chaleur est donc infime.
- En définitive, la topologie Classe D a prouvé sa capacité à encoder et amplifier fidèlement le signal audio tout en garantissant un rendement énergétique maximal. Cet étage de puissance répond en tout point aux exigences de notre cahier des charges pour l'amplification embarquée de la guitare acoustique.

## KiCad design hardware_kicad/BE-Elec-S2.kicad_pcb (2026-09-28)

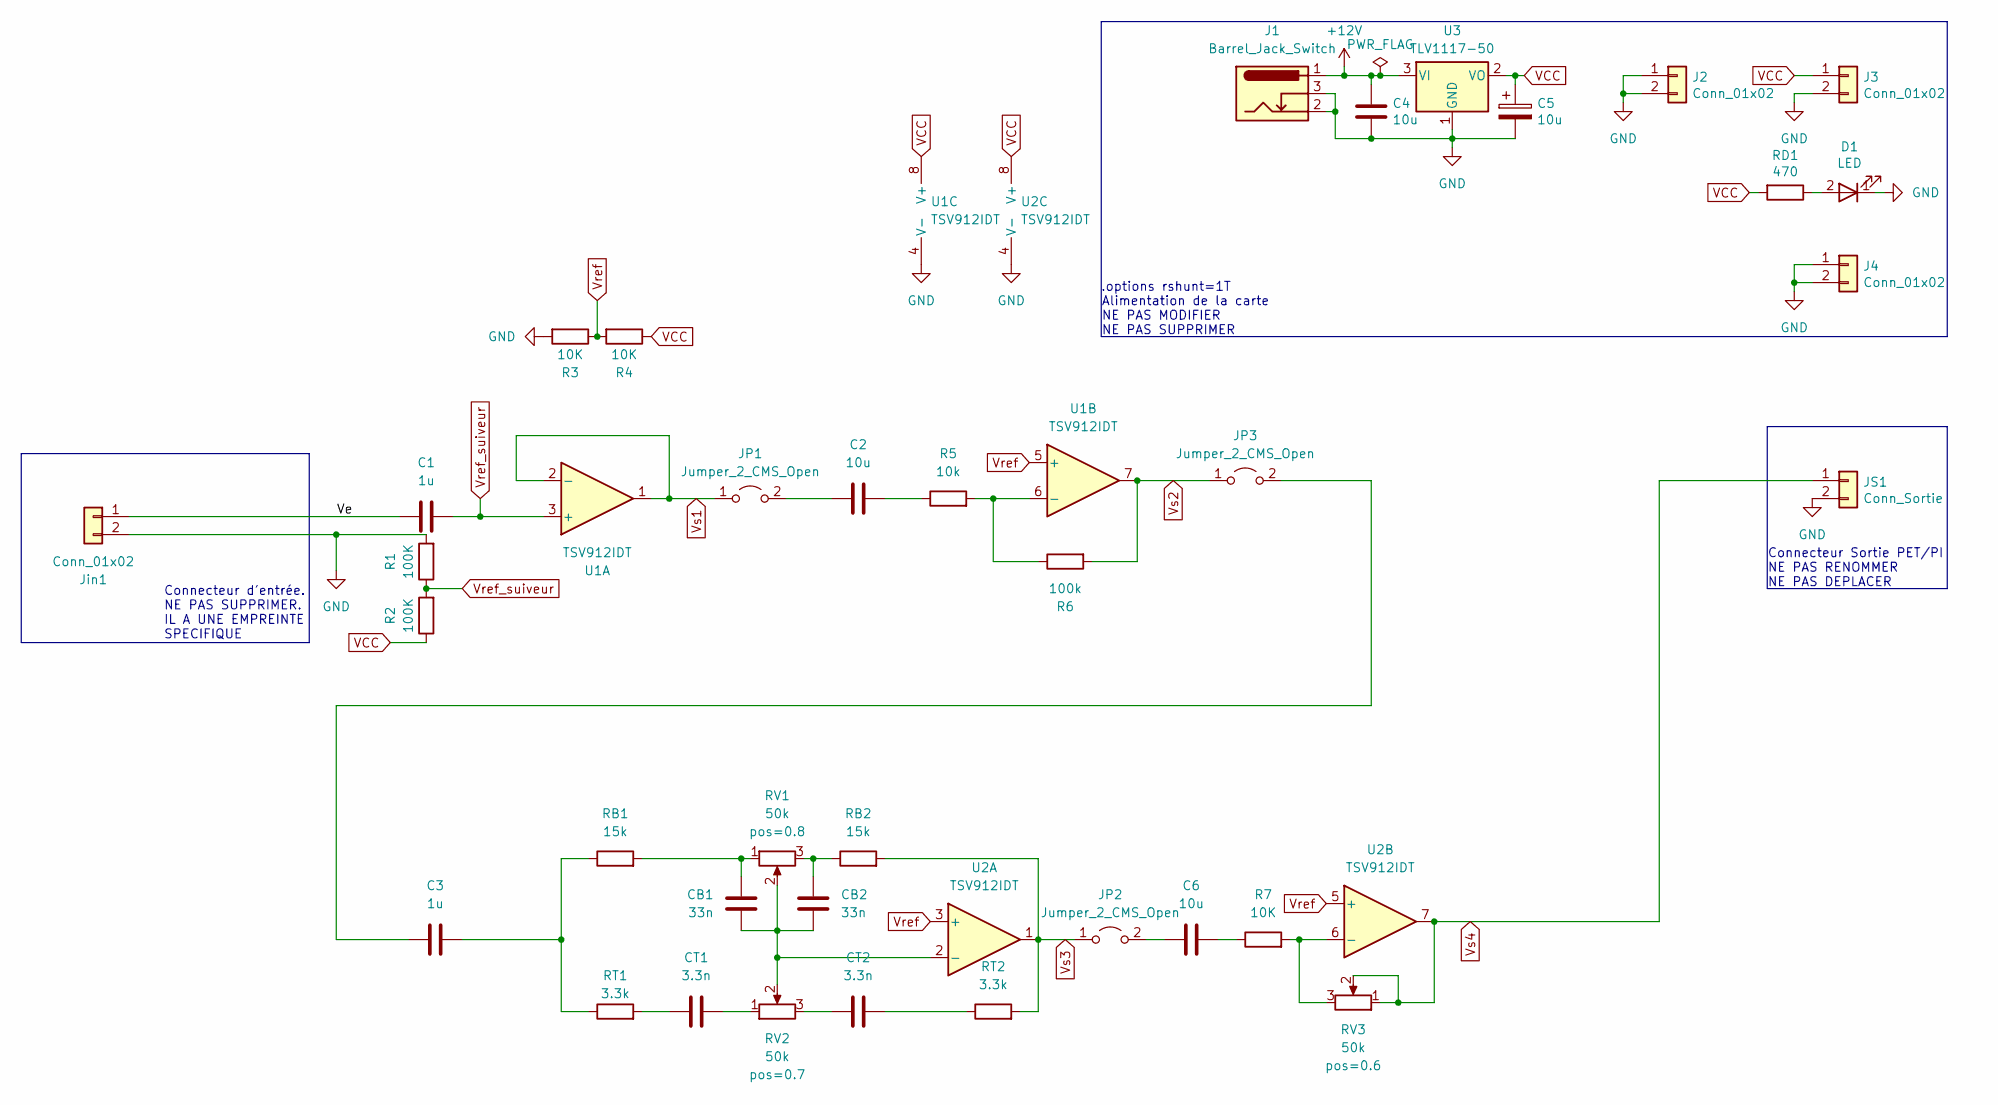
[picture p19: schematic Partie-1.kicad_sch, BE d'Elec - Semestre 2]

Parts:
C1, C3: 1u; C_1206_3216Metric_Pad1.42x1.75mm_HandSolder
C2, C4, C6: 10u; C_1206_3216Metric_Pad1.42x1.75mm_HandSolder
C5: 10u; CP_Elec_6.3x5.2
CB1, CB2: 33n; C_1206_3216Metric_Pad1.42x1.75mm_HandSolder
CT1, CT2: 3.3n; C_1206_3216Metric_Pad1.42x1.75mm_HandSolder
D1: LED; LED_1206_3216Metric_Pad1.42x1.75mm_HandSolder
J1: Barrel_Jack_Switch; BarrelJack_CLIFF_FC681465S_SMT_Horizontal
J2, J3, J4: Conn_01x02; PinHeader_1x02_P2.54mm_Vertical
JP1, JP2, JP3: Jumper_2_CMS_Open; SolderJumper-2_P1.3mm_Open_TrianglePad1.0x1.5mm
JS1: Conn_Sortie; PinHeader_1x02_P2.54mm_Vertical
Jin1: Conn_01x02; PinHeader_1x02_P2.54mm_Vertical
R1, R2: 100K; R_1206_3216Metric_Pad1.42x1.75mm_HandSolder
R3, R4, R7: 10K; R_1206_3216Metric_Pad1.42x1.75mm_HandSolder
R5: 10k; R_1206_3216Metric_Pad1.42x1.75mm_HandSolder
R6: 100k; R_1206_3216Metric_Pad1.42x1.75mm_HandSolder
RB1, RB2: 15k; R_1206_3216Metric_Pad1.42x1.75mm_HandSolder
RD1: 470; R_1206_3216Metric_Pad1.42x1.75mm_HandSolder
RT1, RT2: 3.3k; R_1206_3216Metric_Pad1.42x1.75mm_HandSolder
RV1, RV2, RV3: 50k; Potentiometer_Vishay_TS53YL_Vertical
U1, U2: TSV912IDT; SOIC-8_3.9x4.9mm_P1.27mm
U3: TLV1117-50; SOT-223-3_TabPin2

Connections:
+12V: C4.1, J1.1, U3.3 (VI)
/Partie-1/Ve: C1.1, Jin1.1
GND: C4.2, C5.2, D1.1 (K), J1.2, J1.3, J2.1, J2.2, J3.2, J4.1, J4.2, JS1.2, Jin1.2, R1.2, R3.2, U1.4 (V-), U2.4 (V-), U3.1 (GND); also elsewhere on the board
unnamed: C2.2, R5.1
unnamed: C3.2, RB1.1, RT1.1
unnamed: C6.2, R7.1
unnamed: CB1.2, RB1.2, RV1.1
unnamed: CB2.2, RB2.1, RV1.3
unnamed: CT1.1, RT1.2
unnamed: CT1.2, RV2.1
unnamed: CT2.1, RV2.3
unnamed: CT2.2, RT2.1
unnamed: D1.2 (A), RD1.1
unnamed: C2.1, JP1.2 (B)
unnamed: C6.1, JP2.2 (B)
unnamed: C3.1, JP3.2 (B)
unnamed: R5.2, R6.1, U1.6 (-)
unnamed: CB1.1, CB2.1, RV1.2, RV2.2, U2.2 (-)
unnamed: R7.2, RV3.3, U2.6 (-)
VCC: C5.1, J3.1, R2.1, R4.1, RD1.2, U1.8 (V+), U2.8 (V+), U3.2 (VO); also elsewhere on the board
Vref: R3.1, R4.2, U1.5 (+), U2.3 (+), U2.5 (+)
Vref_suiveur: C1.2, R1.1, R2.2, U1.3 (+)
Vs1: JP1.1 (A), U1.1, U1.2 (-)
Vs2: JP3.1 (A), R6.2, U1.7
Vs3: JP2.1 (A), RB2.2, RT2.2, U2.1
Vs4: JS1.1, RV3.1, RV3.2, U2.7

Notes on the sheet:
Connecteur d'entrée. NE PAS SUPPRIMER. IL A UNE EMPREINTE SPECIFIQUE
.options rshunt=1T
Connecteur Sortie PET/PI NE PAS RENOMMER NE PAS DEPLACER
Alimentation de la carte NE PAS MODIFIER NE PAS SUPPRIMER

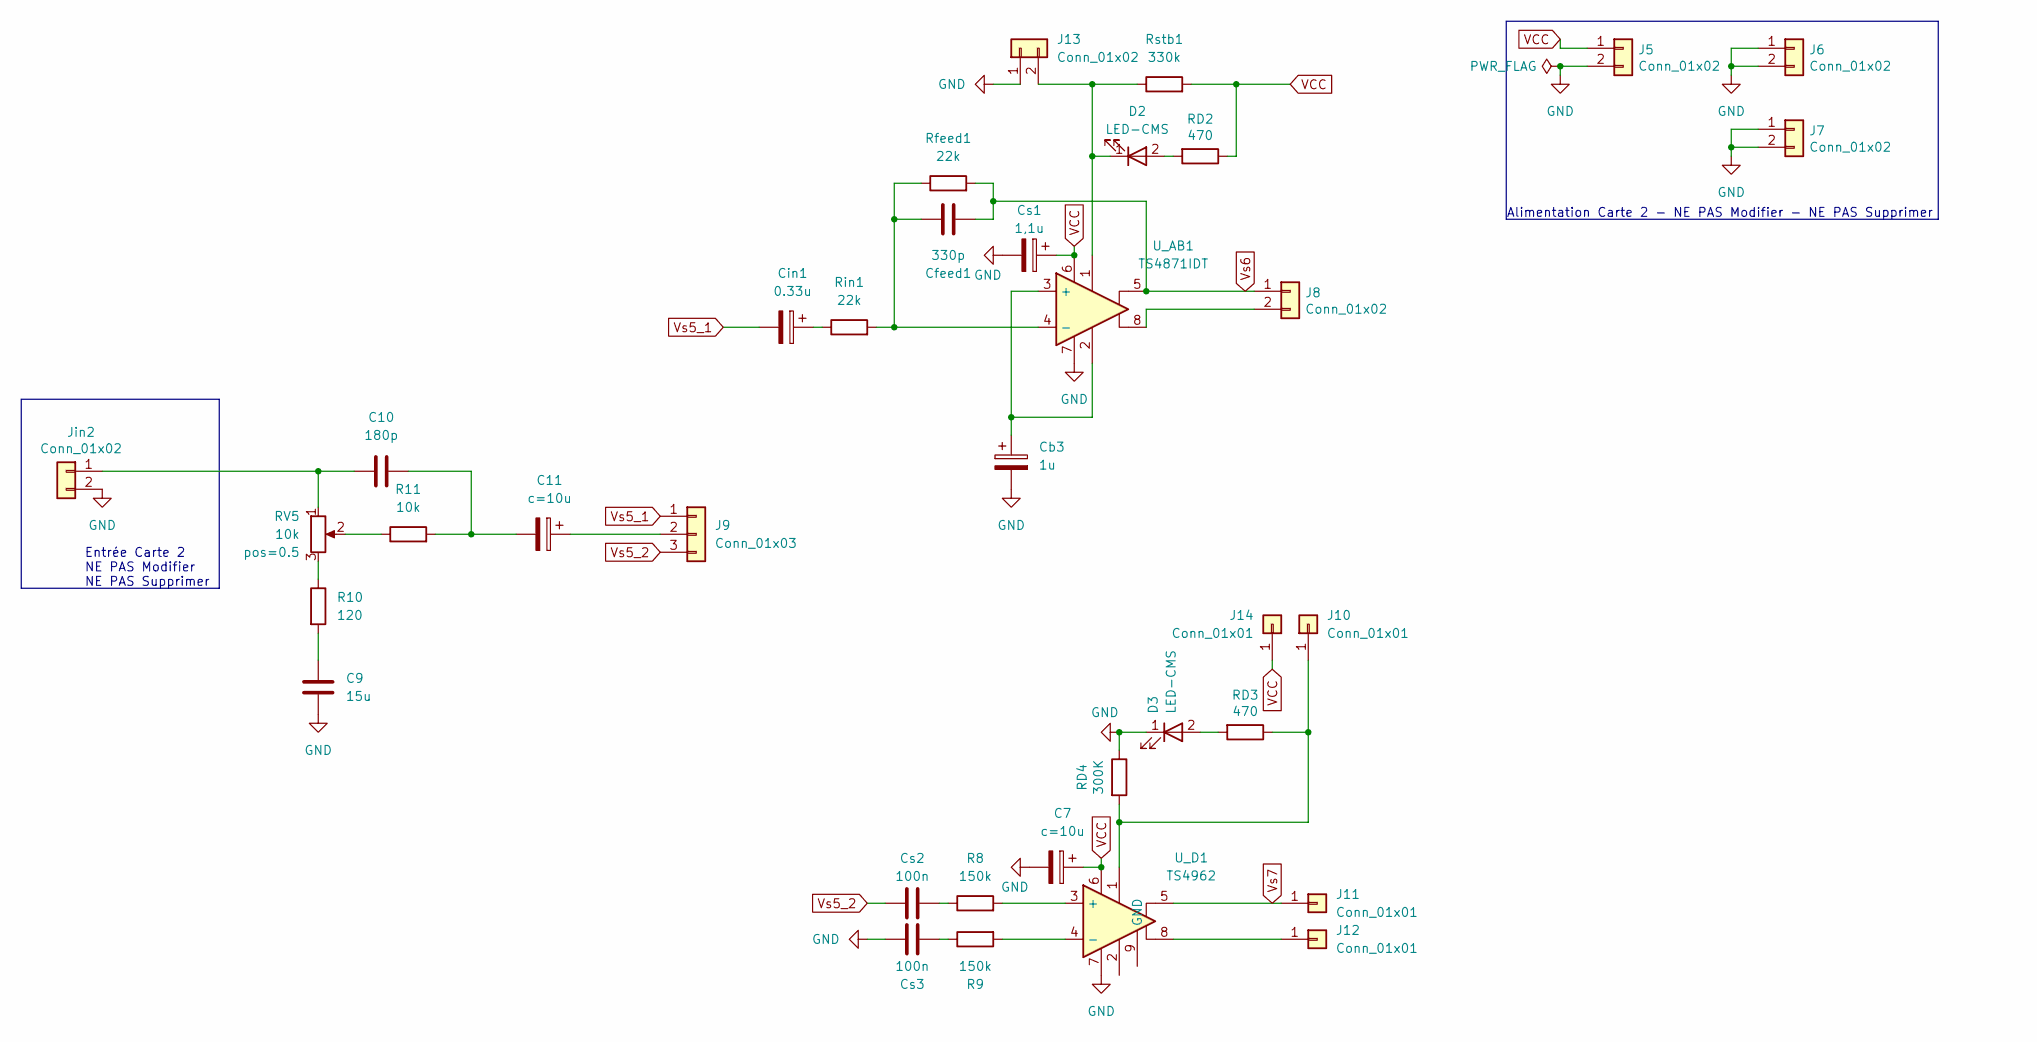
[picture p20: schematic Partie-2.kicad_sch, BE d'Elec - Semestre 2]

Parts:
C7, C11: c=10u; CP_Elec_6.3x5.2
C9: 15u; C_1206_3216Metric_Pad1.42x1.75mm_HandSolder
C10: 180p; C_1206_3216Metric_Pad1.42x1.75mm_HandSolder
Cb3: 1u; CP_Elec_6.3x5.2
Cfeed1: 330p; C_1206_3216Metric_Pad1.42x1.75mm_HandSolder
Cin1: 0.33u; CP_Elec_6.3x5.2
Cs1: 1,1u; CP_Elec_6.3x5.2
Cs2, Cs3: 100n; C_1206_3216Metric_Pad1.42x1.75mm_HandSolder
D2, D3: LED-CMS; LED_1206_3216Metric_Pad1.42x1.75mm_HandSolder
J5, J6, J7, J8, J13: Conn_01x02; PinHeader_1x02_P2.54mm_Vertical
J9: Conn_01x03; PinHeader_1x03_P2.54mm_Vertical
J10, J11, J12, J14: Conn_01x01; PinHeader_1x01_P2.54mm_Vertical
Jin2: Conn_01x02; PinHeader_1x02_P2.54mm_Vertical
R8, R9: 150k; R_1206_3216Metric_Pad1.42x1.75mm_HandSolder
R10: 120; R_1206_3216Metric_Pad1.42x1.75mm_HandSolder
R11: 10k; R_1206_3216Metric_Pad1.42x1.75mm_HandSolder
RD2, RD3: 470; R_1206_3216Metric_Pad1.42x1.75mm_HandSolder
RD4: 300K; R_1206_3216Metric_Pad1.42x1.75mm_HandSolder
RV5: 10k; Potentiometer_Vishay_TS53YL_Vertical
Rfeed1: 22k; R_1206_3216Metric_Pad1.42x1.75mm_HandSolder
Rin1: 22k; R_1206_3216Metric_Pad1.42x1.75mm_HandSolder
Rstb1: 330k; R_1206_3216Metric_Pad1.42x1.75mm_HandSolder
U_AB1: TS4871IDT; SOIC-8_3.9x4.9mm_P1.27mm
U_D1: TS4962; DFN-8-1EP_3x3mm_P0.65mm_EP1.55x2.4mm

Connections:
GND: C7.2, C9.1, Cb3.2, Cs1.2, Cs3.1, D3.1 (K), J5.2, J6.1, J6.2, J7.1, J7.2, J13.1, Jin2.2, RD4.1, U_AB1.7, U_D1.7; also elsewhere on the board
unnamed: C9.2, R10.2
unnamed: C10.2, C11.2, R11.2
unnamed: Cin1.1, Rin1.1
unnamed: Cs2.2, R8.1
unnamed: Cs3.2, R9.1
unnamed: D2.2 (A), RD2.2
unnamed: D2.1 (K), J13.2, Rstb1.1, U_AB1.1
unnamed: D3.2 (A), RD3.2
unnamed: J8.2, U_AB1.8
unnamed: C11.1, J9.2
unnamed: J10.1, RD3.1, RD4.2, U_D1.1
unnamed: J12.1, U_D1.8
unnamed: C10.1, Jin2.1, RV5.1
unnamed: R10.1, RV5.3
unnamed: R11.1, RV5.2
unnamed: Cb3.1, U_AB1.2, U_AB1.3 (+)
unnamed: Cfeed1.1, Rfeed1.1, Rin1.2, U_AB1.4 (-)
unnamed: R8.2, U_D1.3 (+)
unnamed: R9.2, U_D1.4 (-)
VCC: C7.1, Cs1.1, J5.1, J14.1, RD2.1, Rstb1.2, U_AB1.6, U_D1.6; also elsewhere on the board
Vs5_1: Cin1.2, J9.1
Vs5_2: Cs2.1, J9.3
Vs6: Cfeed1.2, J8.1, Rfeed1.2, U_AB1.5
Vs7: J11.1, U_D1.5

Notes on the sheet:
Entrée Carte 2 NE PAS Modifier NE PAS Supprimer
Alimentation Carte 2 - NE PAS Modifier - NE PAS Supprimer

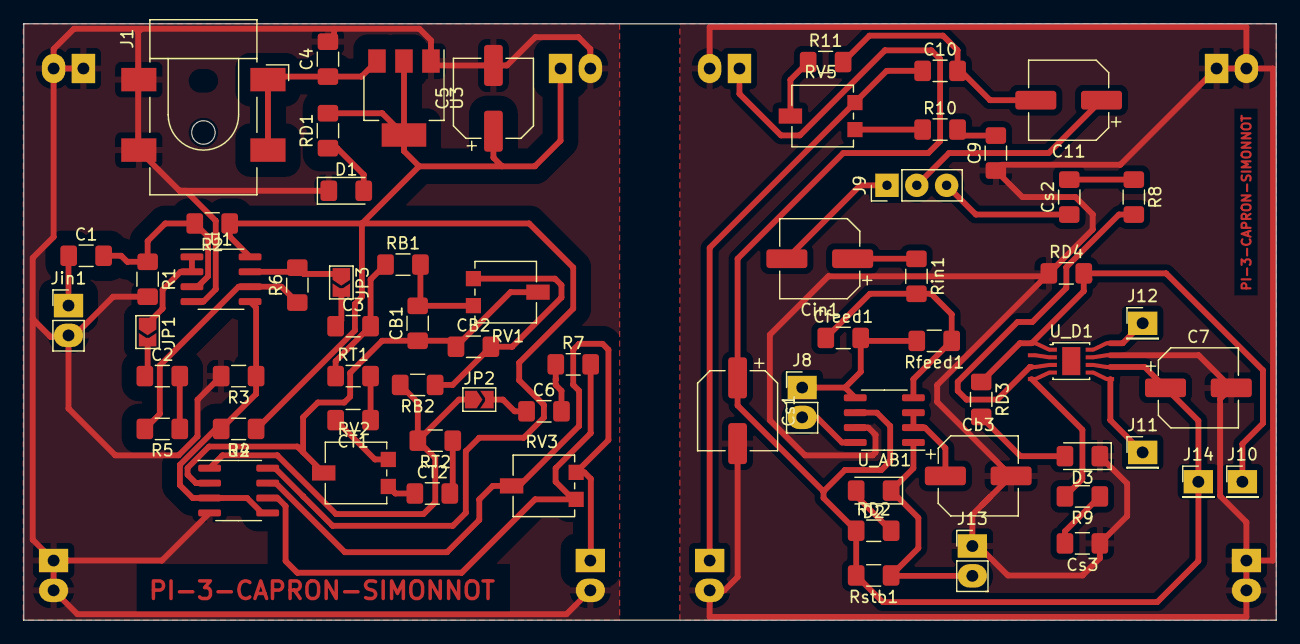
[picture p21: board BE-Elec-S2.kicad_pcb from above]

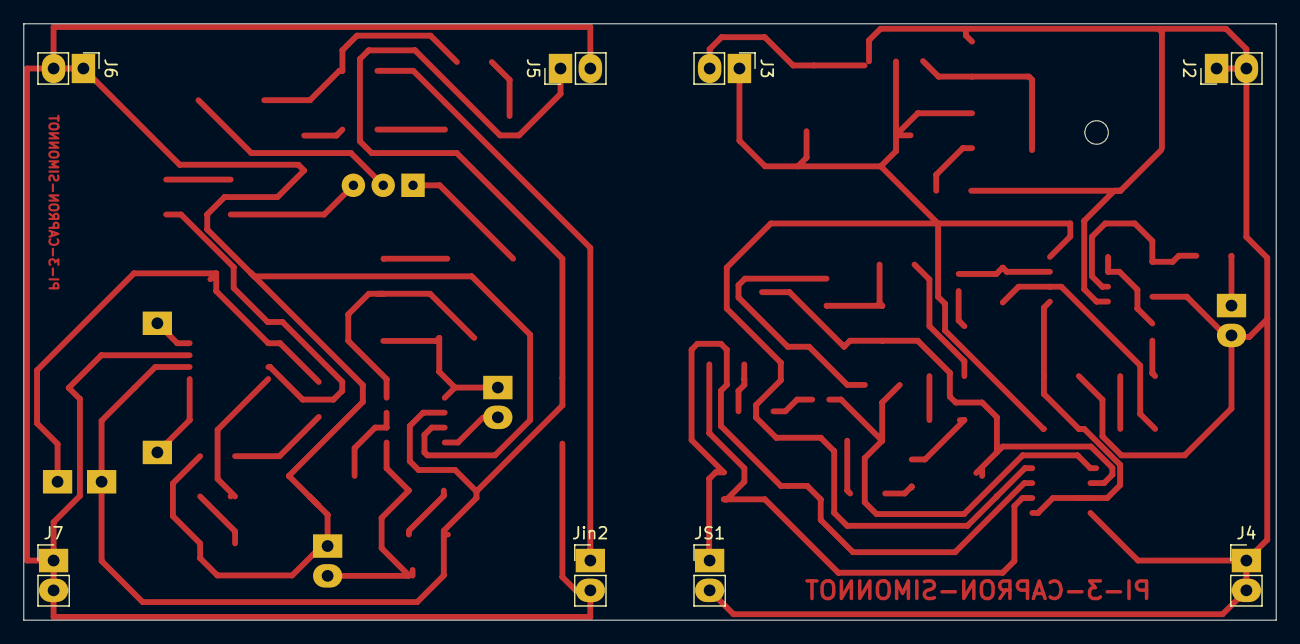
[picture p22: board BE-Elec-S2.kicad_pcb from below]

Board: 4 copper layers, 106.7 x 50.8 mm, 74 parts (8 on the bottom side), 49 nets.

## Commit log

2026-09-28 Ajout des fichiers KiCad 9, des mesures oscilloscope/Bode et de la documentation
    [BE-Elec-S2.kicad_pcb, BE-Elec-S2.kicad_sch, Partie-1.kicad_sch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]
2026-09-28 Ajout des photos des cartes PCB 1 et 2 et mise à jour du README
2026-09-28 Activation de la détection des fichiers KiCad par GitHub Linguist
